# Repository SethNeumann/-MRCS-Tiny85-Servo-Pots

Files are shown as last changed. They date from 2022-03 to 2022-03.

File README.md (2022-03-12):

# REPO NAME: MRCS-Tiny85-Servo-Pots

## License: Creative Commons Attribution-NonCommercial-ShareAlike

A simple servo controller to replace Mark Schutzer's PIC based design for which the PIC has become unavbailable.
This controls an SG90 or similar low cost servo. End travel positions are set with 2 pots.  There is a single
input line which is grounded to reverse the turnout. An onboard push button is provided to easy calibration. In
addition to the servo output a LED is provided with onboard limiting resistor.

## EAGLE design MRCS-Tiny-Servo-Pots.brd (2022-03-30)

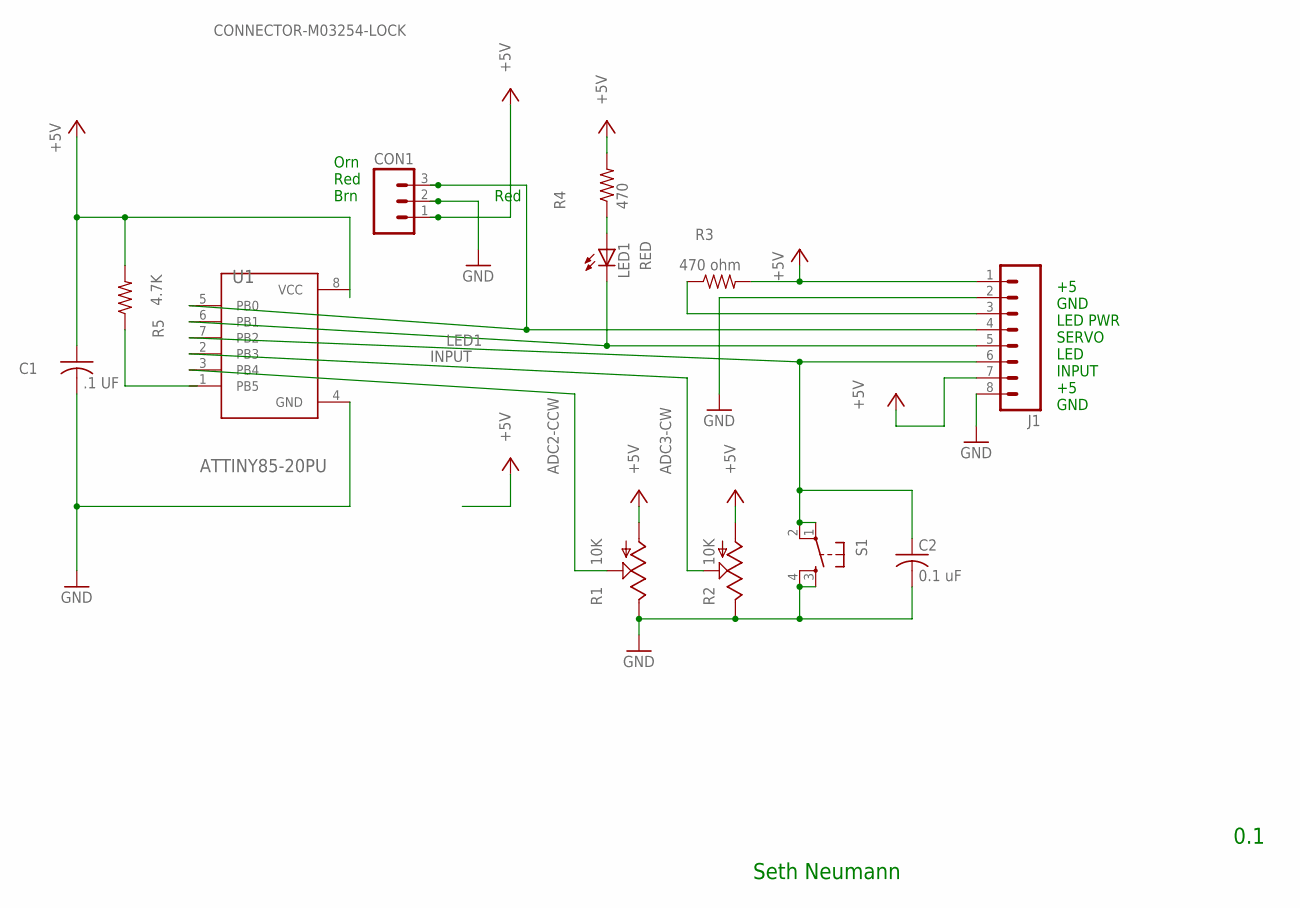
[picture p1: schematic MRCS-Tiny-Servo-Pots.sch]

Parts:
C1: .1 UF; C-PTH-0.100
C2: 0.1 uF; C-PTH-0.100
CON1: CONNECTOR-M03254-LOCK; 3POL254
J1: CONNECTOR-M08LOCK; 1X08_LOCK
LED1: RED; LED3MM
R1, R2: 10K; RS3
R3: 470 ohm; AXIAL-0.4-RES
R4: 470; AXIAL-0.4-RES
R5: 4.7K; AXIAL-0.4-RES
S1: TAC_SWITCHPTH; TACTILE-PTH
U1: ATTINY85-20PU; DIP762W46P254L927H533Q8B

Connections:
+5V: C1.1, CON1.1, J1.1, J1.7, R1.A, R2.A, R3.P$2 (2), R4.P$2 (2), R5.P$2 (2)
ADC2-CCW: R1.S, U1.3 (PB4)
ADC3-CW: R2.S, U1.2 (PB3)
GND: C1.2, C2.2, CON1.2, J1.2, J1.8, R1.E, R2.E, S1.3, S1.4, U1.4 (GND)
INPUT: C2.1, J1.6, S1.1, S1.2, U1.7 (PB2)
LED1: J1.5, LED1.K (C), U1.6 (PB1)
unnamed: J1.3, R3.P$1 (1)
unnamed: LED1.A, R4.P$1 (1)
unnamed: CON1.3, J1.4, U1.5 (PB0)
VCC: U1.8 (VCC)

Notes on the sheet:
Seth Neumann
Red
Orn Red Brn
+5 GND LED PWR SERVO LED INPUT +5 GND
0.1

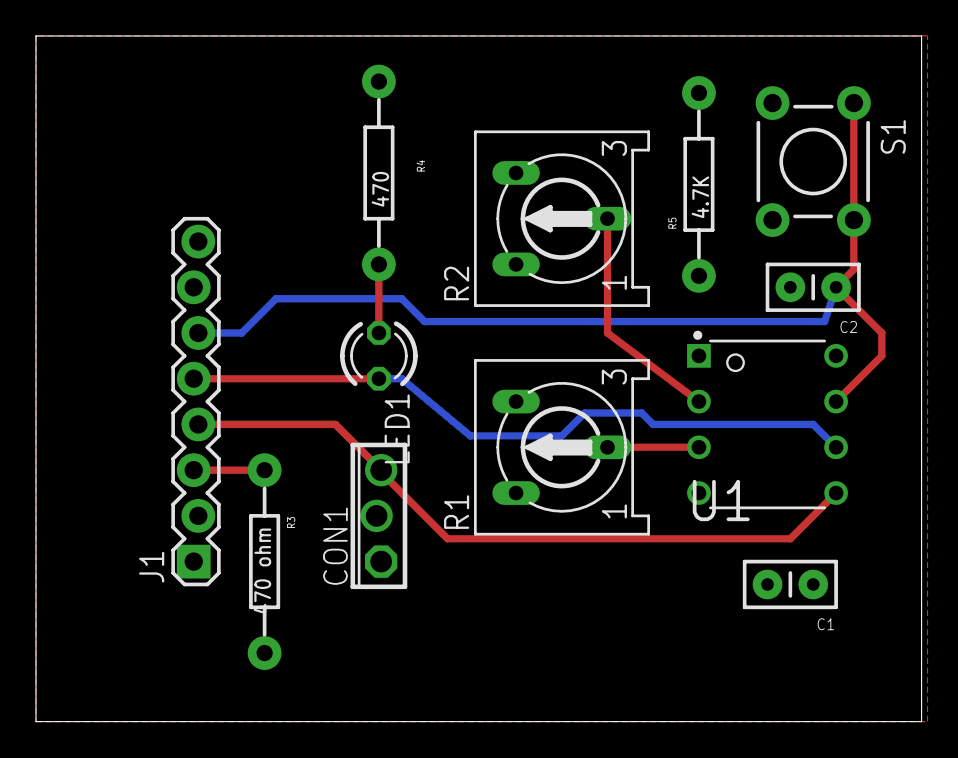
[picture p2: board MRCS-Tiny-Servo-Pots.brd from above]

Board: 2 copper layers, 49.2 x 38.1 mm, 13 parts (0 on the bottom side), 9 nets.

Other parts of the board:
U$1: MRCSLOGOTOP

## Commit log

2022-03-12 initial commit
    move files from another project in as a baseline
    [EagleTemplate-new.brd, EagleTemplate-new.sch, MRCS-Tiny-Servo-Pots.brd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]
2022-03-30 first pass to production
    this one is a little too big to go 2x3 so some changes will be made, also considering going surface mount, but only 2 resistors and a LED, the rest would be thru hole
    [MRCS-Tiny-Servo-Pots.brd, MRCS-Tiny-Servo-Pots.sch]

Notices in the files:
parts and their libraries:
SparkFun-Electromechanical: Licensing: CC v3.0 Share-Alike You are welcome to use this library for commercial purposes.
